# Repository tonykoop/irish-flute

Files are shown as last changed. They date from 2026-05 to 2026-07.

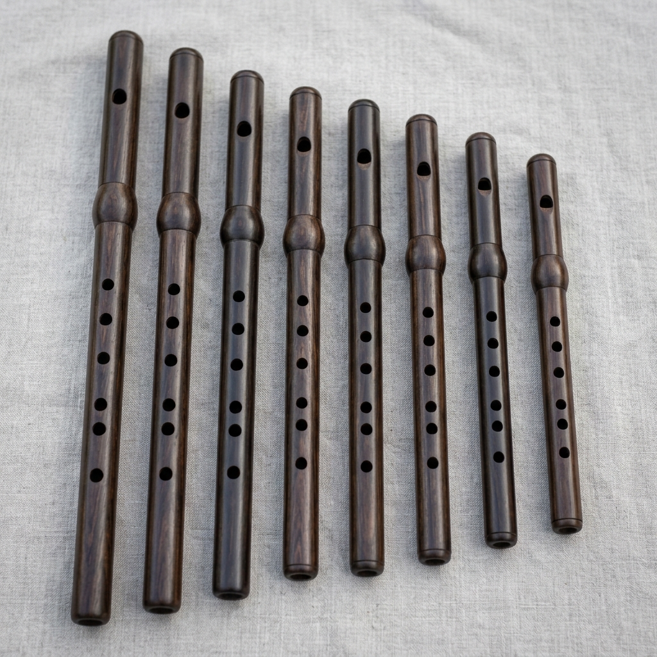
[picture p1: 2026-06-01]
images/family-group.png

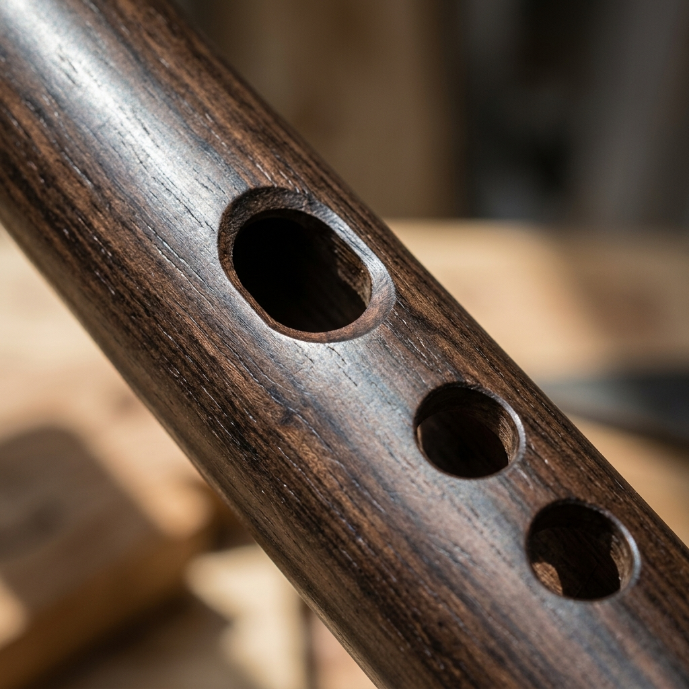
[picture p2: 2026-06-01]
images/macro/embouchure-and-toneholes.png

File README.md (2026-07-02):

# Irish Flute

Engineering build packet for a keyless D4 Irish flute: a six-hole wooden transverse flute with a cylindrical first-pass bore, simple embouchure, and open-pipe acoustic model.

**Status:** L2 V5 build-packet candidate. No prototype measurements, render pass, or source-availability check has been completed. Do not treat the hole positions as build-ready until `validation.csv` is populated. All SVGs are derived previews; Wolfram source is present but runtime execution is not yet recorded.

Part of the [tonykoop/instrument-maker](https://github.com/tonykoop/instrument-maker) catalogue.

## Packet Map

| File / Folder | Purpose |
|---|---|
| `irish-flute-design-table.xlsx` | Existing parametric workbook for the family |
| `design.md` | Governing model, D4 assumptions, first-order tone-hole table |
| `bom.csv` | Materials and shop consumables for one D4 prototype |
| `sourcing.csv` | Sourceability worksheet with verification fields |
| `cut-list.csv` | Stock, bore, embouchure, and tone-hole operations |
| `validation.csv` | Dimensional and tuning checks to fill during the first build |
| `assembly-manual.md` | Shop sequence and gates |
| `drawing-brief.md` | Drawing package requirements |
| `visual-bom-brief.md` | Photo/render plan for the visual BOM |
| `risks.md` | Red-team risks with verification tests |
| `photo-shotlist.md` | Required build photos |
| `resources.md` | Provenance, model sources, and cultural notes |
| `jig-decision.md` | Fixture choices and open setup decisions |
| `drawings/irish-flute-d4-layout.svg` | L2 layout drawing starter |
| `cad/README.md` | CAD starter notes |
| `cad/irish-flute.scad` | Parametric OpenSCAD master (bore envelope + tone-hole schedule); `pending_measurement` |
| `irish-flute-starter.wl` | Wolfram model starter |
| `wolfram/irish-flute-wolfram-model.wl` | Generated Wolfram source package; source-only, not executed |
| `evolution/` | Evolution-pipeline Stage 0 intake: master manifest, design-intent, revision register (Gate A not yet run) |
| `site/index.html` | Static build-log starter |

## Design Snapshot

| Parameter | D4 prototype | Status |
|---|---:|---|
| Fundamental | D4, 293.66 Hz | target |
| Bore ID | 0.750 in | assumption |
| Wall | 0.125 in | assumption |
| Effective acoustic length | 23.08 in | calculated |
| Physical bore length | 22.63 in | first-order |
| Blank length | 24.50 in | includes trim/setup allowance |
| Tone holes | 6 front holes | first-order |
| Construction | Reamed hardwood tube, hand-cut embouchure | L2 plan |

## Build Posture

This packet uses the open-open cylindrical pipe model from instrument-maker-v4.3. It intentionally excludes Tony's NAF K2 corrections because those are specific to Native American style flutes with slow-air chambers. Irish flute tuning depends strongly on embouchure cut, bore finish, hole diameter, and player technique, so the values here are starting geometry only.

## License

[CC BY 4.0](LICENSE) - see LICENSE for details.

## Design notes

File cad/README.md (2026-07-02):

# Irish Flute CAD Starter

`irish-flute.scad` is a parametric OpenSCAD master (V5 refresh, 2026-07-01):
open-open cylindrical bore envelope (formulas from design.md's governing
model) plus the six tone holes from design.md's Tone-Hole First Pass table.
It is `pending_measurement` authority — not fabrication-ready until reviewed
against a measured D4 prototype.

## Parameters (see cad/irish-flute.scad header)

- `bore_id_in = 0.750 in`
- `body_od_in = 1.000 in`
- `L_bore_in` — computed from `c_in_per_sec` and `f_root_hz` (design.md
  governing model), not a baked value.
- `tone_holes` — distance-from-foot + starter diameter per hole, from
  design.md's table.

## Scope Boundary (still not modeled — build these by hand)

1. Embouchure cut feature with editable bevel — tuning-sensitive, out of
   scope for this starter (design.md A2).
2. Tone-hole undercutting/voicing — holes are drawn at starter diameters
   only; tune by opening incrementally (design.md A3).
3. Optional ergonomic exterior shaping.

Rebuild the model from the measured D4 prototype (not just the first-order
table) once `validation.csv` has real fundamental and per-hole pitch data.

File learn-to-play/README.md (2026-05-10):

# learn-to-play / Irish Flute (D)

Starter songbook for the **6-hole D Irish flute** from the [`irish-flute`](https://github.com/tonykoop/irish-flute) build packet. Generated by the [`sheet-music`](https://github.com/tonykoop/sheet-music) skill.

The Irish flute is a simple-system wooden flute in D — similar to a tin whistle in fingering but with a more breathy, open tone and slower response.

Range: **D5 – D7** (two octaves). Key of D major / D mixolydian.

## Folder map
| Folder | Contents |
|---|---|
| `00-warmup-scales/` | Range walk, interval study, trill-and-cut drill |
| `01-easy/` | Three slow PD tunes |
| `02-intermediate/` | Two session tunes with ornaments |
| `03-original/` | *Bog Road Reel* — Heifer Zephyr original |
| `fingering-charts.svg` | Full D-major fingering chart, D5–D7 |

## Repertoire

### 01-easy
| Tune | Tradition |
|---|---|
| Star of the County Down | Trad Irish (pre-1900), D mixolydian |
| The Wren Song | Trad Irish (An Dreoilín, pre-1900) |
| Ode to Joy | Beethoven (1824), adapted D major |

### 02-intermediate
| Tune | Tradition |
|---|---|
| Si Bheag Si Mhor | Turlough O'Carolan (c.1720) |
| The Sally Gardens | Trad Irish / Yeats (pre-1900 melody) |

### 03-original
**Bog Road Reel** — 32-bar reel, A major, ♩=120.

## License
Arrangements MIT-licensed by Tony Koop / Heifer Zephyr. PD tunes: provenance in each `notes.md`.

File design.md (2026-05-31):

# Irish Flute - Design Document

**Instrument:** Keyless Irish flute  
**Prototype target:** D4 six-hole wooden transverse flute  
**Family:** Open-open cylindrical pipe, transverse embouchure  
**Packet version:** instrument-maker-v4.3 root-mode L2 scaffold  
**Readiness:** Design packet only. Physical validation pending.

## Governing Model

The first-pass acoustic model treats the flute as an open-open cylindrical pipe:

```text
f = c / (2 * L_eff)
L_eff = c / (2 * f)
L_bore = L_eff - 2 * (0.6 * r)
```

At 68 F / 20 C, `c = 13552 in/s`. For D4 at 293.66 Hz:

| Quantity | Value | Notes |
|---|---:|---|
| `L_eff` | 23.08 in | acoustic length |
| Bore ID | 0.750 in | D4 prototype assumption |
| Radius | 0.375 in | derived |
| Total end correction | 0.450 in | two open ends |
| `L_bore` | 22.63 in | first-order physical bore |
| Trim/setup allowance | 1.87 in | do not cut short |
| Rough blank | 24.50 in | stock prep target |

Do not apply NAF K2 corrections. The Irish flute has no slow-air chamber, and the transverse embouchure creates a different end-correction regime.

## Tone-Hole First Pass

Distances are measured from the open foot end to the hole center. Hole diameters are intentionally conservative; final tuning is by measured pitch and incremental opening/undercutting.

| Hole | Note | Freq Hz | Distance From Foot In | Distance From Foot Mm | Starter Diameter In | Status |
|---|---:|---:|---:|---:|---:|---|
| 1 | E4 | 329.63 | 2.58 | 65.5 | 0.250 | estimate |
| 2 | F#4 | 369.99 | 4.76 | 120.9 | 0.281 | estimate |
| 3 | G4 | 392.00 | 5.77 | 146.6 | 0.281 | estimate |
| 4 | A4 | 440.00 | 7.68 | 195.1 | 0.313 | estimate |
| 5 | B4 | 493.88 | 9.38 | 238.3 | 0.313 | estimate |
| 6 | C#5 | 554.37 | 10.89 | 276.6 | 0.313 | estimate |

Formula used:

```text
distance_from_foot = L_eff * (1 - f_root / f_hole)
```

## Assumptions And Known Gaps

| ID | Assumption / Gap | Impact | Resolution |
|---|---|---|---|
| A1 | Bore is cylindrical at 0.750 in ID | Real Irish flutes often use conical/tapered behavior | Keep this as D4 prototype baseline; add tapered-body variant after measurements |
| A2 | Embouchure correction is represented by ordinary open-end correction | Fundamental may be off after cutting the embouchure | Measure the bored blank and update `validation.csv` before drilling holes |
| A3 | Hole diameters are starter values | Notes may be flat until holes are opened | Drill undersize and tune up incrementally |
| A4 | Wall thickness 0.125 in | Structural crack risk around embouchure and holes | Verify wall with calipers after boring |
| A5 | D4 is the primary build | Other keys remain workbook-only | Add family members after D4 measured data exists |

## Cross-References

- Workbook: `irish-flute-design-table.xlsx`
- Layout starter: `drawings/irish-flute-d4-layout.svg`
- Wolfram starter: `irish-flute-starter.wl`
- Build sequence: `assembly-manual.md`
- Validation worksheet: `validation.csv`

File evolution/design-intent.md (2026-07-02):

# Design Intent — irish-flute rev A

- Master CAD: `cad/irish-flute.scad` (sha256: f6063eaa2beac330208694ebef8f406d11d7c9bcca66b0f07274039c1f69dd89), driven by `design.md` governing model + `irish-flute-design-table.xlsx` (sha256: ff5f6c298f1c7fad84eeeb5f1f2fa9e5dd4fb7b002ebf7af7879a9d59cc673fc)
- Function: Keyless six-hole wooden transverse flute, D4 root, modeled as an open-open cylindrical pipe (`f = c/(2*L_eff)`). No slow-air chamber; transverse embouchure gives a different end-correction regime than NAF-style flutes (design.md explicitly excludes NAF K2 corrections).
- Environment: hand-held wind instrument; wood body, cylindrical bore, tuned by incremental hole-opening after boring.
- Target qty: 1 (D4 prototype). Deadline: TBD. Budget/unit ceiling: TBD.

## Critical dimensions (carry tolerances)

| Feature | Nominal | Tolerance | Why critical | Source |
| --- | --- | --- | --- | --- |
| Bore ID | 0.750 in | measured after boring, before final cut | intonation/wall strength | design.md Governing Model (design_table_backed) |
| L_eff (acoustic length) | 23.08 in | derived from f_root=293.66 Hz | fundamental pitch | design.md formula (design_table_backed) |
| L_bore (physical bore) | 22.63 in | +1.87 in trim/setup allowance before final cut | fundamental pitch, do not cut short | design.md Governing Model (design_table_backed) |
| Tone hole 1 (E4) | 2.58 in from foot, 0.250 in dia | drill undersize, tune by opening (risks.md AC-01) | intonation | design.md Tone-Hole First Pass table (measurement_required) |
| Tone hole 4 (A4) | 7.68 in from foot, 0.313 in dia | drill undersize, tune by opening (risks.md AC-01) | intonation | design.md Tone-Hole First Pass table (measurement_required) |
| Wall thickness | 0.125 in | verify with calipers after boring (design.md A4) | crack risk near embouchure/holes | design.md Assumptions (measurement_required) |

## Incidental (free for DFM)

- Exterior finish (Danish oil/shellac), ergonomic exterior shaping outside the bore/hole geometry, cosmetic body profile.

## Must-nots (DFM may never violate)

- Do not apply NAF K2 bore corrections — the Irish flute's transverse embouchure has a different end-correction regime (design.md Governing Model).
- Do not cut the body to final length before the embouchure is tested on scrap and fundamental is measured (risks.md AC-02; design.md A2 "measure the bored blank... before drilling holes").
- Do not drill tone holes to final diameter directly — pilot undersize, tune by opening incrementally, one hole at a time (risks.md AC-01, design.md A3).
- Do not skip the scrap-blank bore validation before boring tonewood (risks.md ST-01, bom.csv item 2 "mandatory before tonewood").
- Embouchure window/bevel and tone-hole undercutting are out of scope for cad/irish-flute.scad — hand-refine and play-test (design.md A2/A3; cad/README.md Scope Boundary).

## Material intent

- Preferred: blackwood/cherry/maple hardwood body blank (bom.csv item 1).
- Acceptable subs: poplar/pine for the mandatory scrap/practice bore blank (bom.csv item 2).
- Forbidden: none recorded beyond the practice-blank-before-tonewood sequencing above.

## Stage status

Stage 0 intake complete 2026-07-01. Gate A (Alpha shop compile) NOT yet run — no concessions logged, nothing presented as shippable. Packet remains L2 per README until the D4 prototype is built, measured, and validation.csv is populated (risks.md Release Gate).

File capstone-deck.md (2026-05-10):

# Slide 1 - Irish Flute D4

L2 engineering packet for a keyless D4 Irish flute.

# Slide 2 - Project Intent

Create a measurable first prototype with open-pipe physics, clear shop gates, and validation rows for every tuning claim.

# Slide 3 - Acoustic Model

Open-open cylindrical pipe, `f = c/(2*L_eff)`, with ordinary open-end correction at both ends.

# Slide 4 - Build Sequence

Scrap bore, tonewood bore, turn from bore axis, cut embouchure, measure fundamental, drill and tune one hole at a time.

# Slide 5 - Packet Files

README, design, BOM, sourcing, cut list, validation worksheet, drawings starter, CAD notes, risks, and photo plan.

# Slide 6 - Materials

Hardwood blank, scrap blank, long 3/4 in bit, optional reamer, tone-hole bits, bore finish, exterior finish.

# Slide 7 - Drawings

The current drawing is an L2 layout starter. Embouchure and fixture drawings remain open until shop measurements exist.

# Slide 8 - Risks

Top risks are bore wander, embouchure effective-length error, and irreversible tone-hole over-opening.

# Slide 9 - Validation

Pitch, bore, wall, and ergonomic checks are captured in `validation.csv`.

# Slide 10 - Sourceability

Supplier rows are not verified. Prices, lead times, and stock must be checked before purchasing.

# Slide 11 - Readiness

L2 scaffold only. Not build-ready until the first prototype is measured.

# Slide 12 - Next Actions

Verify tooling, run scrap bore, cut embouchure on scrap, then update the workbook and validation sheet from measured data.

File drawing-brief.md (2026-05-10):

# Irish Flute Drawing Brief

## Required Drawings

| Drawing | Status | Notes |
|---|---|---|
| D4 layout drawing | starter present | `drawings/irish-flute-d4-layout.svg` |
| Embouchure detail | TBD | Add section and bevel geometry after scrap test |
| Bore setup drawing | TBD | Add lathe/drill fixture after shop setup selected |
| Tone-hole jig drawing | TBD | Add V-block and stop reference dimensions |

## Drafting Requirements

- Units: inches, with millimeter equivalents for critical dimensions.
- Datums: foot end for tone-hole positions; bore axis for all radial dimensions.
- Mark all tone-hole positions as first-order estimates.
- Include a title block with packet version and L2 readiness.

## Critical Dimensions

| Dimension | Value | Status |
|---|---:|---|
| Bore ID | 0.750 in | assumption |
| OD | 1.000 in | target |
| Physical bore length | 22.63 in | first-order |
| Rough blank length | 24.50 in | shop |
| H1 from foot | 2.58 in | estimate |
| H6 from foot | 10.89 in | estimate |

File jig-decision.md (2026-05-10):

# Irish Flute Jig Decisions

| Decision | Selected Path | Why | Open Check |
|---|---|---|---|
| Bore setup | Lathe-supported long drill through square blank | Keeps bore axis as later turning datum | Validate with scrap blank |
| Tone-hole setup | Drill press V-block with foot-end stop | Repeatable hole spacing from foot datum | Build stop after actual body OD known |
| Embouchure workholding | Padded V-block plus hand tools | Allows conservative acoustic refinement | Add drawing after scrap test |
| Tuning workflow | One hole at a time | Prevents irreversible over-opening | Record each step in validation worksheet |

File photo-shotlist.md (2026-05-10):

# Irish Flute Photo Shotlist

| Shot ID | Stage | Shot | Purpose |
|---|---|---|---|
| P01 | Materials | Hardwood blank with end grain visible | Document stock quality |
| P02 | Materials | Tooling laid out | Visual BOM |
| P03 | Setup | Blank mounted for bore operation | Safety/process evidence |
| P04 | Scrap | Scrap bore exit measurement | Bore-wander validation |
| P05 | Body | Tonewood after boring | Process record |
| P06 | Body | Turned OD with calipers | Dimensional evidence |
| P07 | Embouchure | Window before bevel | Geometry record |
| P08 | Embouchure | Beveled edge close-up | Voicing evidence |
| P09 | Layout | Hole layout marks from foot datum | Traceability |
| P10 | Tuning | Tuner reading for fundamental | Validation evidence |
| P11 | Finished | Full instrument side view | README/site hero candidate |
| P12 | Finished | Detail of embouchure and first holes | Build-log detail |

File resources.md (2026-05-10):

# Irish Flute Resources And Provenance

The Irish flute is a living traditional instrument associated with Irish dance music and session practice. This packet documents a shop prototype and does not claim to reproduce a specific historic maker's bore, undercutting, or tonal style.

## Model Sources

- instrument-maker-v4.3 `acoustic-models.md`: open-open cylindrical pipe and tone-hole first pass.
- Common D4 flute sanity check: a D4 Irish flute is roughly 23 in acoustic length, depending on headjoint, bore, and embouchure.

## Public-Release Notes

- Keep all first-order geometry marked as estimated until a prototype is measured.
- Do not claim traditional equivalence from this engineering scaffold.
- Add references for any copied historic measurements before publishing them as source-backed values.

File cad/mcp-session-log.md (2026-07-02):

# CAD / MCP Session Log — irish-flute

No external MCP or creative-tool sessions have produced artifacts in this packet as of 2026-05-29.
The SVG in `drawings/` was generated from the design-table by a prior sprint agent without an
interactive OpenSCAD MCP, Blender MCP, Illustrator MCP, or image-gen session.

When an OpenSCAD MCP, Blender MCP, or image-gen session produces or modifies a repo artifact,
add a row to the table below before committing that artifact.

| session_id | tool | input_authority | outputs | role | authority_result | review_status | notes |
|---|---|---|---|---|---|---|---|
| — | — | — | — | — | — | — | No sessions recorded. |
| fable-v5-refresh-2026-07-01 | claude-code (Fable 5) | irish-flute-design-table.xlsx, bom.csv, sourcing.csv, cut-list.csv, validation.csv | bom.csv, sourcing.csv, cut-list.csv, validation.csv | packet_refresh | fabrication | self_checked | V5 refresh pass: README status-line format fixed (bold-colon bug); tabular packet data reviewed against design-table baseline, no dimension changes made. |
| fable-v5-refresh-2026-07-01 | claude-code (Fable 5) + OpenSCAD CLI | design.md, family-spec.csv, cut-list.csv | cad/irish-flute.scad | cad_authoring | pending_measurement | self_checked | Authored new parametric master (no prior .scad existed): open-open cylindrical bore envelope (parametric L_eff/L_bore formulas per design.md) + design.md's six-hole tone-hole schedule. Embouchure/undercutting explicitly out of scope. openscad render check: pass (openscad -o STL, exit 0; L_eff=23.0743in, L_bore=22.6243in, matching design.md's 23.08/22.63). |
| fable-v5-refresh-2026-07-01 | claude-code (Fable 5) + generate_wolfram_packet.py | irish-flute-design-table.xlsx, family-spec.csv, validation.csv | wolfram/irish-flute-wolfram-model.wl | analysis_source | derived_preview | unreviewed | Generated via $SKILL/generate_wolfram_packet.py (not executed — no --execute passed); renamed from instrument-model.wl; source-only L2 evidence, distinct from existing irish-flute-starter.wl. |

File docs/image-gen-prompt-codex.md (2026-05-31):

# Image Generation Prompt

Concept visualization only. Do not treat generated images as dimensional, tuning, CAD, DXF, or fabrication authority.

## Hero Prompt

Photorealistic studio product photograph of a keyless D Irish flute prototype, a simple six-hole wooden transverse flute with dark polished hardwood body, cylindrical first-pass bore, clean embouchure hole, plain open foot, and no metal keys. Arrange it on a neutral linen surface with a small cork-grease tin and tuner as scale cues, clean studio background, soft directional studio lighting, three-quarter product-photography angle, about a 50mm lens, high detail.

## In-Context Prompt

Photorealistic scene of the Irish flute on a workbench beside a reamer, drill bits, calipers, and a validation sheet with no readable text. Natural window light, realistic woodshop setting, the six-hole transverse body and hand-cut embouchure visible, environmental storytelling around tuning by drilling undersize and measuring pitch.

## Detail/Macro Prompt

Close-up macro of the Irish flute embouchure: crisp oval blow hole cut into polished hardwood, subtle bore edge visible inside, smooth wall thickness, nearby finger hole softly blurred, realistic grain and tool marks, high-detail photorealistic studio light.

## Negative / Avoid

Avoid logos, watermarks, readable text, silver concert-flute keywork, recorder mouthpieces, extra holes, impossible bore taper claims, distorted hands, and fabrication dimension overlays.

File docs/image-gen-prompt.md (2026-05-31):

# Image-Gen Prompts

Concept image only; not fabrication authority. Do not include cut-ready dimensions, hole locations, or toolpaths.

## Hero Prompt

A keyless wooden Irish flute presented as a single finished instrument, photographed as a real physical object: a slender transverse flute roughly the length of a forearm-and-a-half, turned from dark close-grained hardwood (grenadilla or ebonite-like deep brown-black) with a warm satin-oiled sheen and fine straight grain running the length of the body. The defining feature is the simple keyless layout — one oval embouchure hole near the closed head end with a crisply hand-cut, slightly undercut blowing edge, and a single straight row of six round open tone holes along the front of the body, no metal keywork or pads anywhere. The bore reads as a clean cylindrical tube; the open foot end is plain and unadorned. Subtle hand-finishing cues at the head and foot suggest a turned, oiled wooden tube rather than a machined part. Clean neutral light-grey studio background, soft directional studio light grazing the body to bring out grain and the carved embouchure, 3/4 product-photography angle, approximately 50mm lens, high detail, photorealistic, no text labels.

## In-Context Prompt

The same keyless wooden Irish flute resting across a worn wooden workbench in a small luthier's workshop, alongside a long boring reamer and a hand chisel suggestive of the embouchure-cutting stage, wood shavings nearby. Warm natural window light from the side, shallow depth of field with the carved embouchure and first tone holes in sharp focus and the tools softly blurred behind. Environmental storytelling of a hand-built session flute; concept visualization only, no measurement markings.

## Detail Prompt

Macro close-up of the flute's signature voicing detail: the oval embouchure hole and the closely spaced first one or two open tone holes, showing the crisp hand-cut blowing edge, the gentle interior undercut of the embouchure window, the satin-oiled dark hardwood grain, and the clean rounded rim of each open hole bored straight through the wall. Raking light across the surface to reveal grain, tool sheen, and the slight chamfer of the cut edges, high detail, shallow focus, no measurements or callouts.

## Family Group Prompt

A graduated set of keyless wooden Irish flutes of the same design lying parallel on a neutral surface, ordered by length to imply different keys of the same family — the realized D4 prototype as the reference instrument among slightly longer and shorter siblings. All share the identical visual language: dark oiled hardwood tubes, a single oval embouchure near each head, and one straight row of six open front tone holes, no keywork. Soft even studio light, top-down 3/4 angle, family-portrait composition, photorealistic, no text labels.

## Negative / Avoid

No text, logos, watermarks, or fake maker marks; no dimension lines or measurement callouts; no metal keys, pads, rods, or saxophone-style keywork; no impossible bore or hole geometry; if hands appear, anatomically plausible with a realistic transverse flute hold.

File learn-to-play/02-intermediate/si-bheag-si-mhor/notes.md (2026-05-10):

# Si Bheag Si Mhor (She Was Small, She Was Great)

**Composer:** Turlough O'Carolan (c.1720); harpist and composer (1670–1738)
**Public domain:** Yes — pre-1929 (US); O'Carolan died 1738
**Arrangement:** G major for D Irish flute. Range G4–G5.

## Range check
G4 is accessed by cross-fingering on the D flute (three fingers, left hand only).
F#5 uses the standard F# fingering (hole 5 open). All notes are achievable.

## Practice tip
O'Carolan tunes have a harp-like quality: long, singing lines. Don't break the
phrases at bar lines — let each four-bar arch build and resolve as one breath.

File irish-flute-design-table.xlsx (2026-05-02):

Irish Wooden Flute |  | Key →
Variable | Unit | 42 | 43 | 44 | 45 | 46 | 47 | 48 | 49 | 50 | 51 | 52 | 53 | 54 | 55 | 56 | 57 | 58 | 59 | 60 | 61 | 62 | 63 | 64 | 65 | 66
Key Name |  | D 4 | D# 4 | E 4 | F 4 | F# 4 | G 4 | G# 4 | A 4 | A# 4 | B 4 | C 5 | C# 5 | D 5 | D# 5 | E 5 | F 5 | F# 5 | G 5 | G# 5 | A 5 | A# 5 | B 5 | C 6 | C# 6 | D 6
Piano Key # |  | 42 | 43 | 44 | 45 | 46 | 47 | 48 | 49 | 50 | 51 | 52 | 53 | 54 | 55 | 56 | 57 | 58 | 59 | 60 | 61 | 62 | 63 | 64 | 65 | 66
PHYSICAL DIMENSIONS
Blank Length | in
Blank Width | in
Blank Thickness | in
Bore ID | in | 0.748 | 0.748 | 0.748 | 0.748 | 0.669 | 0.669 | 0.669 | 0.669 | 0.591 | 0.591 | 0.591 | 0.591 | 0.591 | 0.512 | 0.512 | 0.512 | 0.512 | 0.512 | 0.433 | 0.433 | 0.433 | 0.433 | 0.433 | 0.433 | 0.433
Wall Thickness | in | 0.250 | 0.250 | 0.250 | 0.250 | 0.236 | 0.236 | 0.236 | 0.236 | 0.197 | 0.197 | 0.197 | 0.197 | 0.197 | 0.177 | 0.177 | 0.177 | 0.177 | 0.177 | 0.157 | 0.157 | 0.157 | 0.157 | 0.157 | 0.157 | 0.157
Turned Diameter | in
Embouchure Hole Dia | in | 0.472 | 0.472 | 0.472 | 0.472 | 0.433 | 0.433 | 0.433 | 0.433 | 0.394 | 0.394 | 0.394 | 0.394 | 0.394 | 0.354 | 0.354 | 0.354 | 0.354 | 0.354 | 0.315 | 0.315 | 0.315 | 0.315 | 0.315 | 0.315 | 0.315
Embouchure Position | in | 1.122 | 1.122 | 1.122 | 1.122 | 1.004 | 1.004 | 1.004 | 1.004 | 0.887 | 0.887 | 0.887 | 0.887 | 0.887 | 0.768 | 0.768 | 0.768 | 0.768 | 0.768 | 0.650 | 0.650 | 0.650 | 0.650 | 0.650 | 0.650 | 0.650
Extra Length | in | 1.000 | 1.000 | 1.000 | 1.000 | 1.000 | 1.000 | 1.000 | 1.000 | 1.000 | 1.000 | 1.000 | 1.000 | 1.000 | 1.000 | 1.000 | 1.000 | 1.000 | 1.000 | 1.000 | 1.000 | 1.000 | 1.000 | 1.000 | 1.000 | 1.000
ACOUSTIC CALCULATIONS
Acoustic Length | in
End Correction (×2) | in
Effective Length | in
Speed of Sound (68°F) | in/s | 13552 | 13552 | 13552 | 13552 | 13552 | 13552 | 13552 | 13552 | 13552 | 13552 | 13552 | 13552 | 13552 | 13552 | 13552 | 13552 | 13552 | 13552 | 13552 | 13552 | 13552 | 13552 | 13552 | 13552 | 13552
DIATONIC MAJOR SCALE
Fundamental Note |  | D 4 | D# 4 | E 4 | F 4 | F# 4 | G 4 | G# 4 | A 4 | A# 4 | B 4 | C 5 | C# 5 | D 5 | D# 5 | E 5 | F 5 | F# 5 | G 5 | G# 5 | A 5 | A# 5 | B 5 | C 6 | C# 6 | D 6
Fundamental Freq | Hz
Hole 1 Note (+2) |  | E 4 | F 4 | F# 4 | G 4 | G# 4 | A 4 | A# 4 | B 4 | C 5 | C# 5 | D 5 | D# 5 | E 5 | F 5 | F# 5 | G 5 | G# 5 | A 5 | A# 5 | B 5 | C 6 | C# 6 | D 6 | D# 6 | E 6
Hole 1 Freq | Hz
Hole 1 Diameter | in
Hole 1 Dist from End | in
Hole 2 Note (+4) |  | F# 4 | G 4 | G# 4 | A 4 | A# 4 | B 4 | C 5 | C# 5 | D 5 | D# 5 | E 5 | F 5 | F# 5 | G 5 | G# 5 | A 5 | A# 5 | B 5 | C 6 | C# 6 | D 6 | D# 6 | E 6 | F 6 | F# 6
Hole 2 Freq | Hz
Hole 2 Diameter | in
Hole 2 Dist from End | in
Hole 3 Note (+5) |  | G 4 | G# 4 | A 4 | A# 4 | B 4 | C 5 | C# 5 | D 5 | D# 5 | E 5 | F 5 | F# 5 | G 5 | G# 5 | A 5 | A# 5 | B 5 | C 6 | C# 6 | D 6 | D# 6 | E 6 | F 6 | F# 6 | G 6
Hole 3 Freq | Hz
Hole 3 Diameter | in
Hole 3 Dist from End | in
Hole 4 Note (+7) |  | A 4 | A# 4 | B 4 | C 5 | C# 5 | D 5 | D# 5 | E 5 | F 5 | F# 5 | G 5 | G# 5 | A 5 | A# 5 | B 5 | C 6 | C# 6 | D 6 | D# 6 | E 6 | F 6 | F# 6 | G 6 | G# 6 | A 6
Hole 4 Freq | Hz
Hole 4 Diameter | in
Hole 4 Dist from End | in
Hole 5 Note (+9) |  | B 4 | C 5 | C# 5 | D 5 | D# 5 | E 5 | F 5 | F# 5 | G 5 | G# 5 | A 5 | A# 5 | B 5 | C 6 | C# 6 | D 6 | D# 6 | E 6 | F 6 | F# 6 | G 6 | G# 6 | A 6 | A# 6 | B 6
Hole 5 Freq | Hz
Hole 5 Diameter | in
Hole 5 Dist from End | in
Hole 6 Note (+11) |  | C# 5 | D 5 | D# 5 | E 5 | F 5 | F# 5 | G 5 | G# 5 | A 5 | A# 5 | B 5 | C 6 | C# 6 | D 6 | D# 6 | E 6 | F 6 | F# 6 | G 6 | G# 6 | A 6 | A# 6 | B 6 | C 7 | C# 7
Hole 6 Freq | Hz
Hole 6 Diameter | in
Hole 6 Dist from End | in
WOLFRAM CLOUD NOTEBOOK SPEC — IRISH FLUTE
6-hole simple-system wooden flute — open-open conical bore, diatonic D major, 25 keys D4–D6.
§1 — Origin & Etymology
Roots: 19th-c. simple-system flute (pre-Boehm), e.g. Pratten/Rudall–Rose/Nicholson designs. Adopted by Irish traditional musicians as cheaper used flutes flooded the market after orchestras switched to Boehm system (~1870 onward).
Distinct from concert flute: keyless or 4–8 keys, conical bore (not cylindrical), wood (blackwood, boxwood, cocus). Nasal/woody timbre well-suited to dance music.
Wolfram items: GeoGraphics over Ireland + UK; TimelinePlot[{1832,1870,1970s}→{Boehm flute, simple-system displaced, Irish trad revival}].
§2 — Physics
Open-open with conical bore: f ≈ c/(2 L_eff). Conical taper boosts higher harmonics — supports octave overblow well.
End correction ΔL ≈ 0.6·r at each open end. Hole positioning: dist = L_acoustic·(f_fund / f_hole).
Wolfram functions: NDSolve Webster horn for conical bore; Periodogram of recorded notes; FindPeaks for octave-key purity.
§3 — Geometry & Materials
Body: typically 4 sections (head + 3 body) or 1-piece. Bore tapers from ~19 mm at head to ~13 mm at foot. Length D4 ≈ 23".
Wood: African blackwood (mpingo) gold standard; cocus, boxwood, polymer. Density and damping affect timbre, weakly affect pitch.
Wolfram items: Manipulate sliders for bore taper, hole sizes, wall thickness; ParametricPlot3D bore as truncated cone.
§4 — Animations
Animate fingering charts: Graphics with hole pattern overlaid on body, cycle through D-major scale showing closed/open holes.
Standing-wave Animate at fundamental + first overblown octave.
§5 — Executable Cells
lFlute[f_, bore_]:=343/(2 f) - 0.6 (bore/2)
holeDist[fFund_, fHole_, L_]:= L (fFund / fHole)
centsErr[measured_, target_]:=1200 Log2[measured/target]
§6 — Wolfram Functions Cheat Sheet
Manipulate, Animate, NDSolve, Periodogram, FindPeaks, NonlinearModelFit, SemanticImport, GeoGraphics, TimelinePlot, CloudDeploy, FormFunction, APIFunction, Export["CDF"].
WOLFRAM EXPLORATIONS — IRISH FLUTE
Curated from the wolfram-notebooks-roadmap brainstorm — pick a row, file an issue, build the notebook.
Roadmap-inspired notebook ideas tailored to this sheet:
• Bore Tone-Color Synthesizer — Impedance-driven harmonic series with wall-reflection coefficients per wood; compare ebony vs blackwood vs cocus vs box.
• Cylindrical-vs-Conical Bore Comparison — Pratten (cylindrical head) vs Rudall-Carte (conical head); predict timbre difference at same fundamental.
• Embouchure-Hole Sensitivity — Sweep undercutting angle + hole area; quantify dynamic range + breath-pressure response.
• Session-Tuning Atlas (D vs Eb) — Multi-key library; show why most session players use D and why some Cape Breton circles prefer C.

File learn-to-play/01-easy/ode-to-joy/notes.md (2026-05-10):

# Ode to Joy

**Tradition:** Beethoven, *Symphony No. 9*, Op.125 (1824)
**Public domain:** Yes — pre-1929 (US)
**Arrangement:** D major for D Irish flute. Range D5–G5 (1st octave).

## Practice tip
On the Irish flute, slower attacks give a rounder tone than a whistle.
Use this tune to practise consistent breath support through the longer note values.

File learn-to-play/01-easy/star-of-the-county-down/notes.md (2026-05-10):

# Star of the County Down

**Tradition:** Trad Irish (pre-1900); D mixolydian modal song
**Public domain:** Yes — traditional melody, pre-1929 (US)
**Arrangement:** D mixolydian for D Irish flute. Range D5–D6.

## Range check
Mostly D5–B5 with one D6. The C-natural (mixolydian b7) sits on the Irish flute's
built-in C-key — no half-holing required.

## Practice tip
Feel the mixolydian colour: the C-natural at bar 5 is the signature moment.
Play it clearly and let it ring — it's what makes this tune sound Irish.

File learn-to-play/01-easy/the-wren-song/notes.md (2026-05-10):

# The Wren Song (An Dreoilín)

**Tradition:** Trad Irish wren-day jig (pre-1900)
**Public domain:** Yes — traditional melody
**Arrangement:** D major jig for D Irish flute. Range D5–A5 (1st octave only).

## Range check
No overblowing — stays entirely in the lower octave.

## Practice tip
A 6/8 jig: feel it as two groups of three. The wren-day tradition is a dance:
once the tune is solid, let your foot tap the dotted-crotchet pulse.

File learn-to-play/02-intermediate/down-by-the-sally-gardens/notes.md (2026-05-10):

# Down by the Sally Gardens

**Tradition:** Trad Irish air; W.B. Yeats poem "Down by the Sally Gardens" (1889)
**Public domain:** Yes — melody traditional pre-1900; Yeats text PD
**Arrangement:** D major for D Irish flute. Range D5–D6.

## Practice tip
A gentle song — keep the tempo unhurried (♩=72 or slower). The long notes are where
the Irish flute's woody tone shines most. Breathe fully before each phrase.

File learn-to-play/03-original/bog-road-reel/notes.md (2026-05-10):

# Bog Road Reel

**Composer:** Tony Koop / Heifer Zephyr (2025)
**License:** MIT — free to perform, record, arrange, and adapt
**Form:** AABB reel, 32 bars, ♩=120
**Instrument:** D Irish flute

## Story
Somewhere between Galway and Clifden there's a road that runs along the bog — peat-black
pools, stone walls, curlews calling. This reel is meant to move at the pace of a bicycle
on that road: steady, deliberate, eyes up.

## Range check
A4–A5 (first octave of a D flute: played as A5–A6 at sounding pitch). No overblowing.

## Practice tip
Start at ♩=80. Work each part (AA, then BB) separately. Reels in sessions push toward
♩=120–140 — reach that only once the notes are effortless.

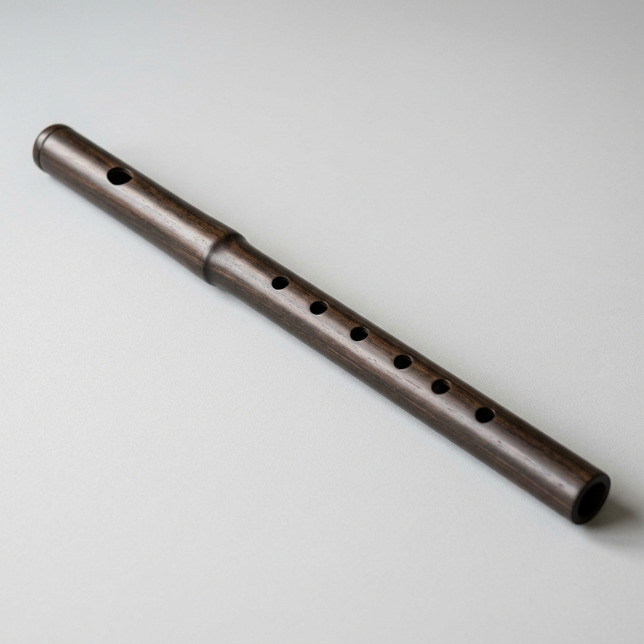
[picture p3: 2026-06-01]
images/hero-render.png

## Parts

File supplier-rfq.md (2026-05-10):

# Irish Flute Supplier RFQ

## Hardwood Blank

Request:

- One or more straight-grained hardwood blanks at least 1.25 x 1.25 x 24.5 in
- Moisture content target: 6-8 percent
- No checks, ring shake, knots, or runout through the bore path
- Species preference: African blackwood if available; cherry, maple, or walnut acceptable for prototype

Questions:

- Is the blank kiln dried?
- Can the supplier provide end-grain photos?
- Is the blank long enough to allow 22.63 in finished bore plus trim allowance?

## Long Bore Tooling

Request:

- 3/4 in aircraft-length drill or gun drill long enough for a 24.5 in blank
- Optional 3/4 in adjustable reamer

Questions:

- What is current lead time?
- What runout tolerance is specified?
- Is the tool suitable for hardwood boring on a lathe setup?

## Finish

Request bore-safe oil or shellac suitable for internal woodwind surfaces. Confirm cure time and contact safety before use.

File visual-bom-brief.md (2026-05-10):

# Irish Flute Visual BOM Brief

## Layout

Create a one-page visual BOM after materials are sourced.

Required panels:

- Full blank with grain direction and marked bore axis
- Long boring bit and reamer
- Embouchure tool set
- Tone-hole bit set
- Bore finish and exterior finish
- Completed flute profile after first build

## Image Requirements

- Neutral background, top-down for parts, 3/4 view for finished body.
- Include a ruler or calipers in process shots where scale matters.
- Label estimated dimensions as "first-order" until `validation.csv` contains measurements.

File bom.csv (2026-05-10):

item_no | part_name | description | qty | unit | material_or_spec | source_class | est_unit_cost_usd | status | notes
1 | D4 body blank | Quarter-sawn hardwood blank for flute body | 1 | ea | Blackwood/cherry/maple 1.25 x 1.25 x 24.5 in | hardwood supplier | 18.00 | TBD | Choose stable straight grain; avoid checks near bore path
2 | Scrap bore blank | Practice blank for boring and embouchure tests | 1 | ea | Poplar or pine 1.25 x 1.25 x 24.5 in | local lumber | 4.00 | TBD | Mandatory before tonewood
3 | Long boring bit | Primary bore drill | 1 | ea | 3/4 in aircraft-length or gun drill | tool supplier | 35.00 | TBD | Verify length and straightness
4 | Adjustable reamer | Final bore sizing | 1 | ea | 3/4 in adjustable reamer | tool supplier | 30.00 | TBD | Optional if boring bit leaves acceptable finish
5 | Tone-hole bit set | Brad-point or twist bits for pilot and final holes | 1 | set | 1/4 in through 5/16 in | hardware | 14.00 | TBD | Use sharp bits only
6 | Embouchure tools | Files/chisels for embouchure window | 1 | set | Needle files and small carving chisel | shop | 0.00 | available | Use existing shop tools
7 | Bore finish | Internal bore oil | 1 | ea | Raw linseed oil or bore oil | hardware/music | 8.00 | TBD | Apply before final tuning checks
8 | Exterior finish | Thin exterior finish | 1 | ea | Danish oil or shellac | hardware | 10.00 | TBD | Avoid heavy finish buildup near holes
9 | Sandpaper | Bore and exterior finishing | 1 | pack | 220/320/400/600 grit | hardware | 6.00 | TBD | Use dowel-backed strips inside bore

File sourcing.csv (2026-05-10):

item_no | item | supplier | supplier_url | search_term_or_part | unit_price_usd | lead_time_days | verified_date | status | notes
1 | Hardwood blank | Woodcraft / Rockler / local mill | https://www.woodcraft.com | 1.25 square turning blank 24 inch | 18.00 | TBD | TBD | TBD | Verify current stock and moisture content before purchase
2 | Scrap blank | Local lumber yard | local | poplar 1.25 square blank | 4.00 | TBD | TBD | TBD | Can be laminated if glue line stays outside bore
3 | 3/4 in long drill | McMaster-Carr / MSC / local machine supplier | https://www.mcmaster.com | 3/4 aircraft length drill 18 inch | 35.00 | TBD | TBD | TBD | Price and availability are time-sensitive
4 | 3/4 in adjustable reamer | McMaster-Carr / MSC | https://www.mcmaster.com | adjustable hand reamer 3/4 inch | 30.00 | TBD | TBD | TBD | Use only if bore finish from drill is poor
5 | Brad point bits | Hardware store / Woodcraft | https://www.woodcraft.com | brad point drill bit set | 14.00 | TBD | TBD | TBD | Sharp bits reduce tearout at tone holes
6 | Bore oil | Music supplier / hardware | https://www.amazon.com | bore oil raw linseed oil | 8.00 | TBD | TBD | TBD | Confirm food/contact suitability

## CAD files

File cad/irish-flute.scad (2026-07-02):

// =============================================================
// Irish Flute — Parametric OpenSCAD Master
// =============================================================
// Source of truth: design.md (Governing Model + Tone-Hole First Pass table),
// family-spec.csv (IFL-D4 row), cut-list.csv (stock/OD).
//
// Authority status: pending_measurement — NOT fabrication authority until
// reviewed against a measured D4 prototype (validation.csv V-FUND and
// per-hole cents-error rows). See cad/mcp-session-log.md for provenance.
//
// SCOPE BOUNDARY (tuning-sensitive geometry intentionally out of scope):
//   - Embouchure window/bevel geometry is NOT modeled here. design.md A2
//     notes the embouchure correction is only an ordinary open-end
//     approximation; real embouchure cutting must be hand-refined and
//     play-tested (cad/README.md "Model Order" step 2).
//   - Tone-hole undercutting/voicing is NOT modeled; holes are drawn at
//     the design.md starter diameters only, "drill undersize and tune
//     up incrementally" (design.md A3).
//   - This is an open-open cylindrical-bore envelope + tone-hole position
//     schedule only, per the instrument-maker starter-generator boundary.
// =============================================================

$fn = 96;

// --------- INPUT PARAMETERS (edit only against design.md / family-spec.csv) ---

// Governing acoustic model (design.md "Governing Model"): open-open
// cylindrical pipe.  f = c / (2*L_eff);  L_eff = c / (2*f);
// L_bore = L_eff - 2*(0.6*r)   [two open-end corrections]
c_in_per_sec      = 13552;   // speed of sound @ 68F/20C (design.md)
f_root_hz         = 293.66;  // D4 target (design.md, family-spec.csv IFL-D4)

bore_id_in        = 0.750;   // D4 prototype bore ID (design.md; family-spec.csv bore_id_mm=19.0)
bore_r_in         = bore_id_in / 2;

body_od_in        = 1.000;   // finished OD (cut-list.csv item 1 final_od_in)
wall_in           = (body_od_in - bore_id_in) / 2;  // = 0.125 in (design.md A4)

L_eff_in          = c_in_per_sec / (2 * f_root_hz);           // acoustic length
end_corr_total_in = 2 * (0.6 * bore_r_in);                    // two open ends
L_bore_in         = L_eff_in - end_corr_total_in;             // first-order physical bore

// Tone-hole schedule — design.md "Tone-Hole First Pass" table.
// [note, freq_hz, distance_from_foot_in, starter_diameter_in]
// distance_from_foot = L_eff * (1 - f_root/f_hole); tabulated in design.md,
// reproduced here as data (not re-derived) so this file matches the
// reviewed design.md table exactly. Diameters are conservative starters —
// "drill undersize and tune up incrementally" (design.md A3).
tone_holes = [
    ["E4",  329.63,  2.58, 0.250],
    ["F#4", 369.99,  4.76, 0.281],
    ["G4",  392.00,  5.77, 0.281],
    ["A4",  440.00,  7.68, 0.313],
    ["B4",  493.88,  9.38, 0.313],
    ["C#5", 554.37, 10.89, 0.313],
];

hole_drill_len_in = wall_in * 4;  // clean through-cut allowance for the diff() cutter

// --------- MODULES ---------------------------------------------------------

// Cylindrical body: OD wall around the bore, length = L_bore_in (first-order;
// design.md notes a further 1.87 in trim/setup allowance before final cut —
// not modeled here, this is the target bore length only).
module flute_body() {
    difference() {
        cylinder(h = L_bore_in, d = body_od_in);
        translate([0, 0, -0.01])
            cylinder(h = L_bore_in + 0.02, d = bore_id_in);
    }
}

// One tone hole, drilled radially at the documented distance from the foot
// (z=0) end, on the +X side of the body.
module tone_hole(distance_from_foot_in, diameter_in) {
    translate([0, 0, distance_from_foot_in])
        rotate([0, 90, 0])
            cylinder(h = hole_drill_len_in, d = diameter_in, center = true);
}

// Top-level assembly: body with all six tone holes cut.
module irish_flute_d4() {
    difference() {
        flute_body();
        for (h = tone_holes) {
            tone_hole(h[2], h[3]);
        }
    }
}

irish_flute_d4();

echo(str("L_eff (acoustic length) = ", L_eff_in, " in"));
echo(str("L_bore (first-order physical bore) = ", L_bore_in, " in"));
echo(str("bore_id = ", bore_id_in, " in;  body_od = ", body_od_in, " in;  wall = ", wall_in, " in"));
echo(str("tone holes modeled: ", len(tone_holes)));

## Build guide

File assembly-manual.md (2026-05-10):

# Irish Flute Assembly Manual

## Build Gates

1. Build and measure the scrap bore before touching tonewood.
2. Cut the embouchure and verify a stable edge tone before drilling tone holes.
3. Drill one tone hole at a time, then measure. Opening a hole raises pitch and cannot be undone.
4. Apply bore finish before final tuning measurements.

## Procedure

### 1. Stock Prep

Select straight-grained, stable stock. Crosscut the tonewood blank and the scrap blank to 24.50 in. Mark centerlines on all four faces and both ends.

### 2. Scrap Bore Validation

Mount the scrap blank using the planned bore setup. Bore to 0.750 in ID with conservative feed and frequent chip clearing. Measure exit wander and bore diameter. If wander exceeds 0.030 in, revise the setup before proceeding.

### 3. Tonewood Bore

Bore the actual blank only after the scrap process passes. Record bore diameter at entry, mid, and exit in `validation.csv`.

### 4. Turn Exterior

Use the bore axis as the datum. Turn the exterior to about 1.000 in OD, leaving local shaping around the embouchure area until voicing is stable.

### 5. Embouchure

Cut the transverse embouchure conservatively. Bevel the far edge and test for a clean edge tone. The embouchure is an acoustic feature, not only a drawing dimension; refine on the scrap blank first.

### 6. Fundamental Check

With the embouchure speaking, measure the all-closed D4 target before tone holes are drilled. If the tube is flat, trim from the foot in small increments. If sharp, stop and document the error before continuing.

### 7. Tone Holes

Lay out holes from the foot using `design.md`. Drill undersize, beginning with hole 1. Measure the note, then open or undercut gradually. Repeat through hole 6.

### 8. Finish And Final Validation

Apply bore oil or shellac, allow it to cure, then remeasure the fundamental and each note. Populate `validation.csv` with measured pitch, cents error, temperature, and notes.

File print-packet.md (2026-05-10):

# Irish Flute D4 - Printable Shop Packet

**Readiness:** L2 scaffold. Bring `validation.csv` to the shop and fill it during the build.

## Critical Sequence

1. Scrap bore validation.
2. Tonewood bore.
3. Turn exterior from bore axis.
4. Cut embouchure and measure D4 fundamental.
5. Drill and tune one tone hole at a time.
6. Finish bore and remeasure.

## Key Numbers

| Parameter | Value |
|---|---:|
| Root | D4, 293.66 Hz |
| Bore ID | 0.750 in |
| Physical bore length | 22.63 in first-order |
| Rough blank | 24.50 in |
| H1 from foot | 2.58 in |
| H6 from foot | 10.89 in |

## Shop Warnings

- Do not apply NAF K2 corrections.
- Do not drill all holes before measuring.
- Do not cut the body short before the embouchure speaks.
- Do not declare L3 readiness without measured validation.

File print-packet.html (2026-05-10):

# Irish Flute D4 Print Packet

Readiness: L2 scaffold. Use with validation.csv; do not treat dimensions as final.

## Sequence

1. Validate scrap bore.
2. Bore tonewood.
3. Turn from bore axis.
4. Cut embouchure and measure D4.
5. Drill and tune one hole at a time.
6. Finish and remeasure.

## Key Numbers

Parameter | Value
Root | D4, 293.66 Hz
Bore ID | 0.750 in
Physical bore length | 22.63 in first-order
Rough blank | 24.50 in

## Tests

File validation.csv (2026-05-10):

check_id | category | parameter | target | tolerance | method | measured | cents_error | pass_fail | date | notes
V-SCRAP-BORE | process | Scrap bore completed before tonewood | yes | required | build log | TBD |  | TBD |  | Do not bore tonewood until this passes
V-BORE-ID | dimensional | Bore ID | 0.750 in | +/-0.005 in | bore gauge | TBD |  | TBD |  | Measure entry/mid/exit
V-BORE-WANDER | dimensional | Bore wander | <0.030 in | maximum | calipers at exit | TBD |  | TBD |  | Reject process if greater than target
V-WALL | dimensional | Minimum wall thickness | >=0.110 in | minimum | calipers | TBD |  | TBD |  | Check around embouchure and tone holes
V-FUND | acoustic | All-closed fundamental | D4 293.66 Hz | +/-5 cents | chromatic tuner | TBD | TBD | TBD |  | Measure before drilling tone holes
V-H1 | acoustic | Hole 1 E4 | 329.63 Hz | +/-10 cents | chromatic tuner | TBD | TBD | TBD |  | Drill undersize and open gradually
V-H2 | acoustic | Hole 2 F#4 | 369.99 Hz | +/-10 cents | chromatic tuner | TBD | TBD | TBD
V-H3 | acoustic | Hole 3 G4 | 392.00 Hz | +/-10 cents | chromatic tuner | TBD | TBD | TBD
V-H4 | acoustic | Hole 4 A4 | 440.00 Hz | +/-10 cents | chromatic tuner | TBD | TBD | TBD |  | A4 sanity check
V-H5 | acoustic | Hole 5 B4 | 493.88 Hz | +/-10 cents | chromatic tuner | TBD | TBD | TBD
V-H6 | acoustic | Hole 6 C#5 | 554.37 Hz | +/-10 cents | chromatic tuner | TBD | TBD | TBD
V-OCTAVE | acoustic | Second register D5 | 587.33 Hz | +/-15 cents | chromatic tuner | TBD | TBD | TBD |  | Assess overblow response
V-FINISH | process | Bore finish cured | no tackiness | required | visual/touch | TBD |  | TBD |  | Recheck pitch after finish cure
V-ERG | ergonomics | Player can cover six holes | yes | required | player test | TBD |  | TBD |  | Record hand-size notes

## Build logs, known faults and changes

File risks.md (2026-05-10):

# Irish Flute Risk Register

## Acoustic Risks

| ID | Risk | Severity | Mitigation | Verification |
|---|---|---|---|---|
| AC-01 | First-order hole positions do not tune on the actual flute | High | Drill undersize and tune one hole at a time | Record cents error for every hole in `validation.csv` |
| AC-02 | Embouchure geometry shifts effective length | High | Test embouchure on scrap and measure fundamental before drilling | V-FUND within tolerance or design updated |
| AC-03 | NAF K2 correction is misapplied | High | Explicitly exclude NAF corrections in `design.md` | Reviewer confirms no K2 offsets in D4 table |

## Structural Risks

| ID | Risk | Severity | Mitigation | Verification |
|---|---|---|---|---|
| ST-01 | Bore wander leaves a thin wall | High | Scrap bore validation before tonewood | V-BORE-WANDER passes |
| ST-02 | Embouchure or tone-hole tearout cracks the body | Medium | Sharp tools, backing support, seal end grain | Visual inspection after each cut |

## Ergonomic And Shop Risks

| ID | Risk | Severity | Mitigation | Verification |
|---|---|---|---|---|
| ER-01 | Hole spread is uncomfortable | Medium | Player reach test before final hole sizing | V-ERG passes |
| SH-01 | Long drill grabs or walks | High | Conservative RPM, peck clearing, secure workholding | Scrap process log accepted |
| SU-01 | Long boring bit unavailable | Medium | Verify source before cutting stock | `sourcing.csv` marked verified |

## Release Gate

This packet remains L2 until the D4 prototype is built, measured, photographed, and the validation worksheet replaces TBD values with actual measurements.

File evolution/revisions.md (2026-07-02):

# Revision Register — irish-flute

| Rev | Date | Parent | Delta | Downstream artifacts invalidated |
| --- | --- | --- | --- | --- |
| A | 2026-07-01 | — | Stage 0 intake of current masters (new cad/irish-flute.scad + irish-flute-design-table.xlsx + newly generated wolfram/irish-flute-wolfram-model.wl). | none (no alpha/beta/production artifacts exist yet) |

Stage 0 only. Gate A has not been run; no Alpha compiles, vendor quotes, or production lock exist for this product.

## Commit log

2026-05-02 Initial scaffold: Irish Flute
    [irish-flute-design-table.xlsx]
2026-05-10 Add Irish flute L2 build packet scaffold (#2)
    [bom.csv, cut-list.csv, sourcing.csv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]
2026-05-29 [irish-flute] V5 uplift: visual-output-register, mcp-session-log, family-spec, L2 status (Refs #1) (#4)
    Add visual-output-register.csv registering irish-flute-d4-layout.svg as derived_preview
    and wolfram-starter.wl as pending_measurement. Add cad/mcp-session-log.md (no external
    tool sessions). Add family-spec.csv L2 scaffold for IFL-D4 member. Update README to
    V5 status line "Status: L2 V5 build-packet candidate".
    Refs #1
    [family-spec.csv, visual-output-register.csv]
2026-05-31 wolfram-rename(irish-flute): unique {slug}-starter.wl + dedupe + ref fixes (cloud-sync naming) (#5)
    [visual-output-register.csv]
2026-05-31 Add image-gen concept prompt; wire explorer images
2026-06-21 Wire 3 rendered concept image(s) into explorer gallery
2026-07-02 V5 packet refresh: status line fix, OpenSCAD master, Wolfram model, provenance, evolution intake
    Validator: python3 validate_v5_packet.py . --slug irish-flute -> 0 failures maintained, 3 pre-existing-style warnings unchanged (all pending_measurement authority WARNs). Fixed README status-line format (bold-colon bug: "**Status: L2...**" -> "**Status:** L2..."), no level change. Authored new cad/irish-flute.scad (no prior .scad existed): parametric open-open cylindrical bore envelope (formulas from design.md governing model) + design.md's six-hole tone-hole schedule; embouchure/undercutting explicitly out of scope; render-checked (openscad -o STL, exit 0; computed L_eff=23.0743in/L_bore=22.6243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
    [irish-flute.scad, visual-output-register.csv]
